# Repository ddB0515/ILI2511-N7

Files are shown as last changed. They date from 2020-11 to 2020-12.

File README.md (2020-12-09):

# ILI2511-N7

Nexus 7(2nd gen) touch controller board based on Ilitek 2511 (only USB and I2C is supported)

# Interactive BOM
[Interactive BOM](http://htmlpreview.github.io/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)

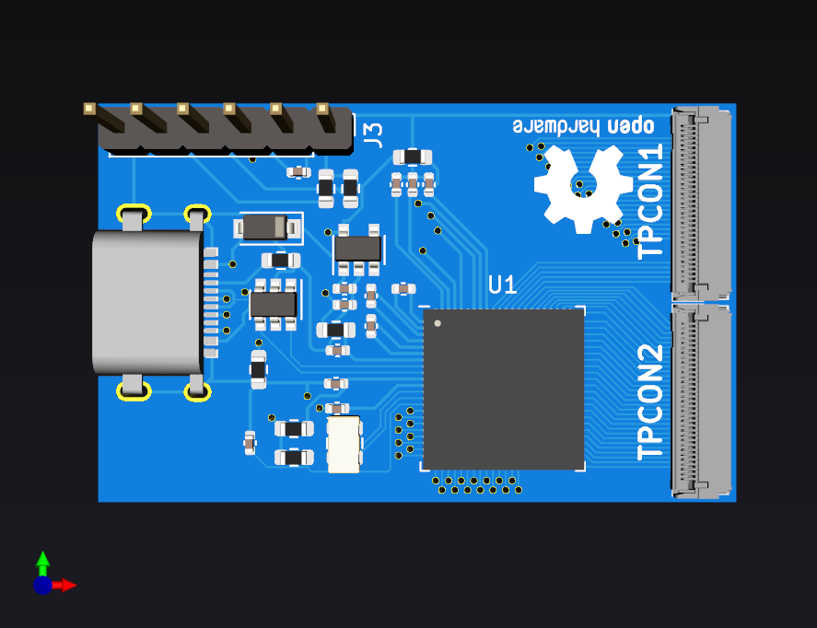
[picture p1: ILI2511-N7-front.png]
Front Photo


## LOG
* v1 inital version
* v2 updated FPC connector (got it working)
* v3 updated footprint to get easier solder and visual check 

## Revisions

 * v1 is currently in testing stage (waiting board to arrive so can test it)
 will update progress here later on
 * v2 working prototype (need slight biggger foorptint for ILI2511)
 * v3 updated footprint and new routing 

## Licence

 * Hardware in this repository is licenced under CERN OHL v1.2

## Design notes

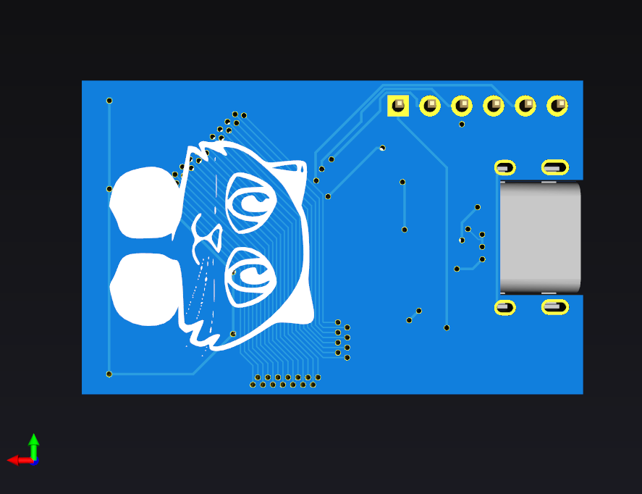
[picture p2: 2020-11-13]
ILI2511-N7-back.png

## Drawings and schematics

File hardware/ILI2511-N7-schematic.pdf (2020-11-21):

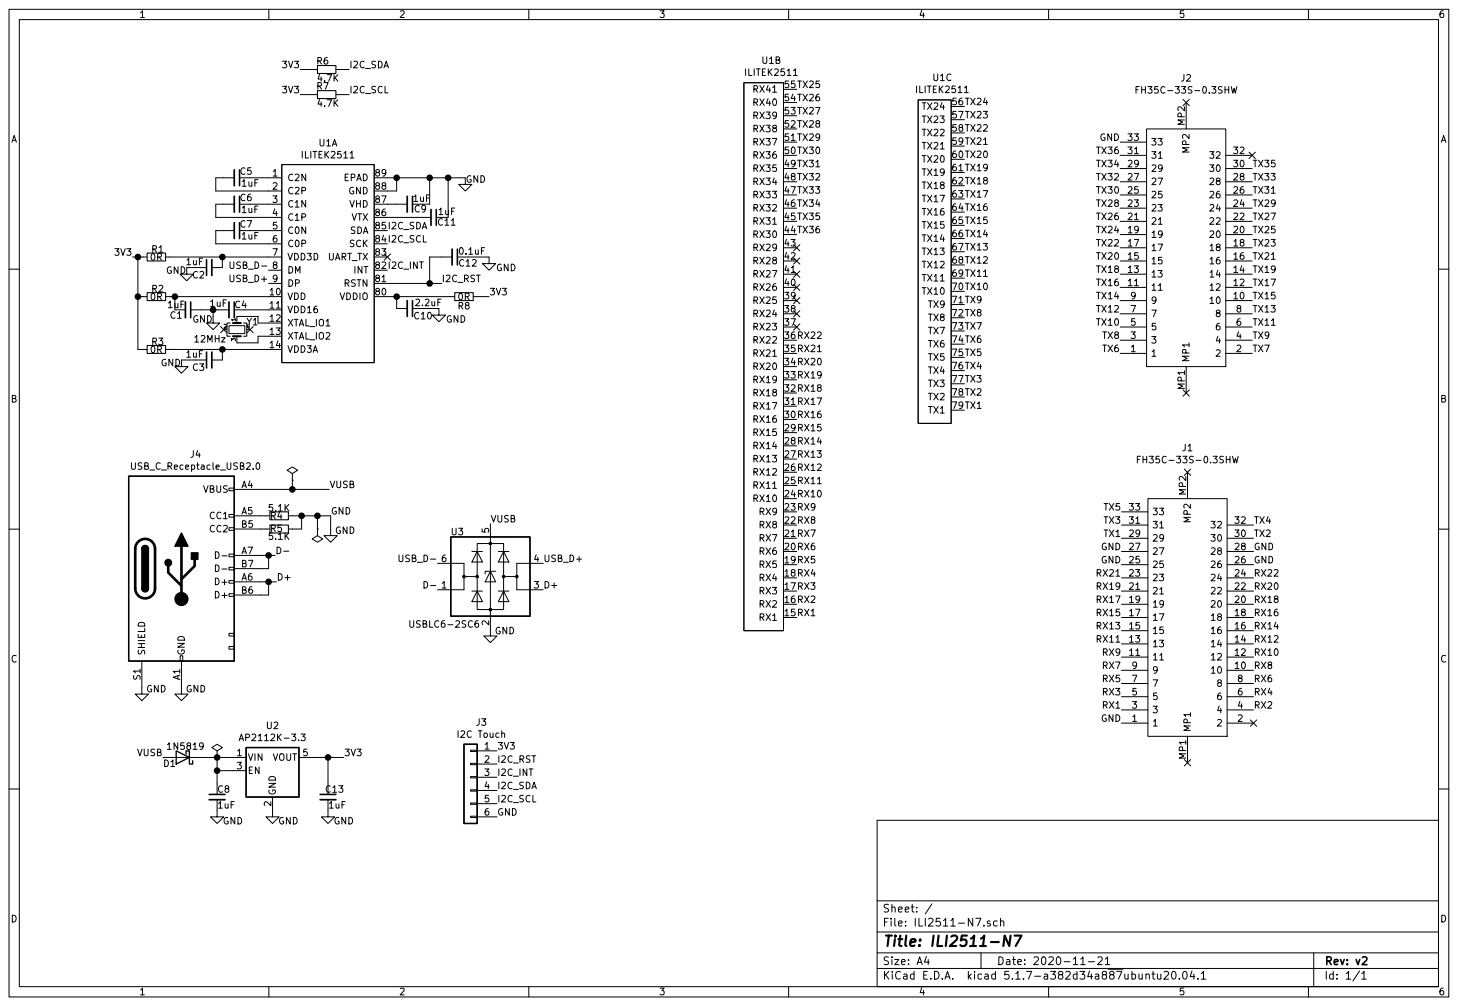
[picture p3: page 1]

File: ILI2511-N7.sch Sheet: / GND

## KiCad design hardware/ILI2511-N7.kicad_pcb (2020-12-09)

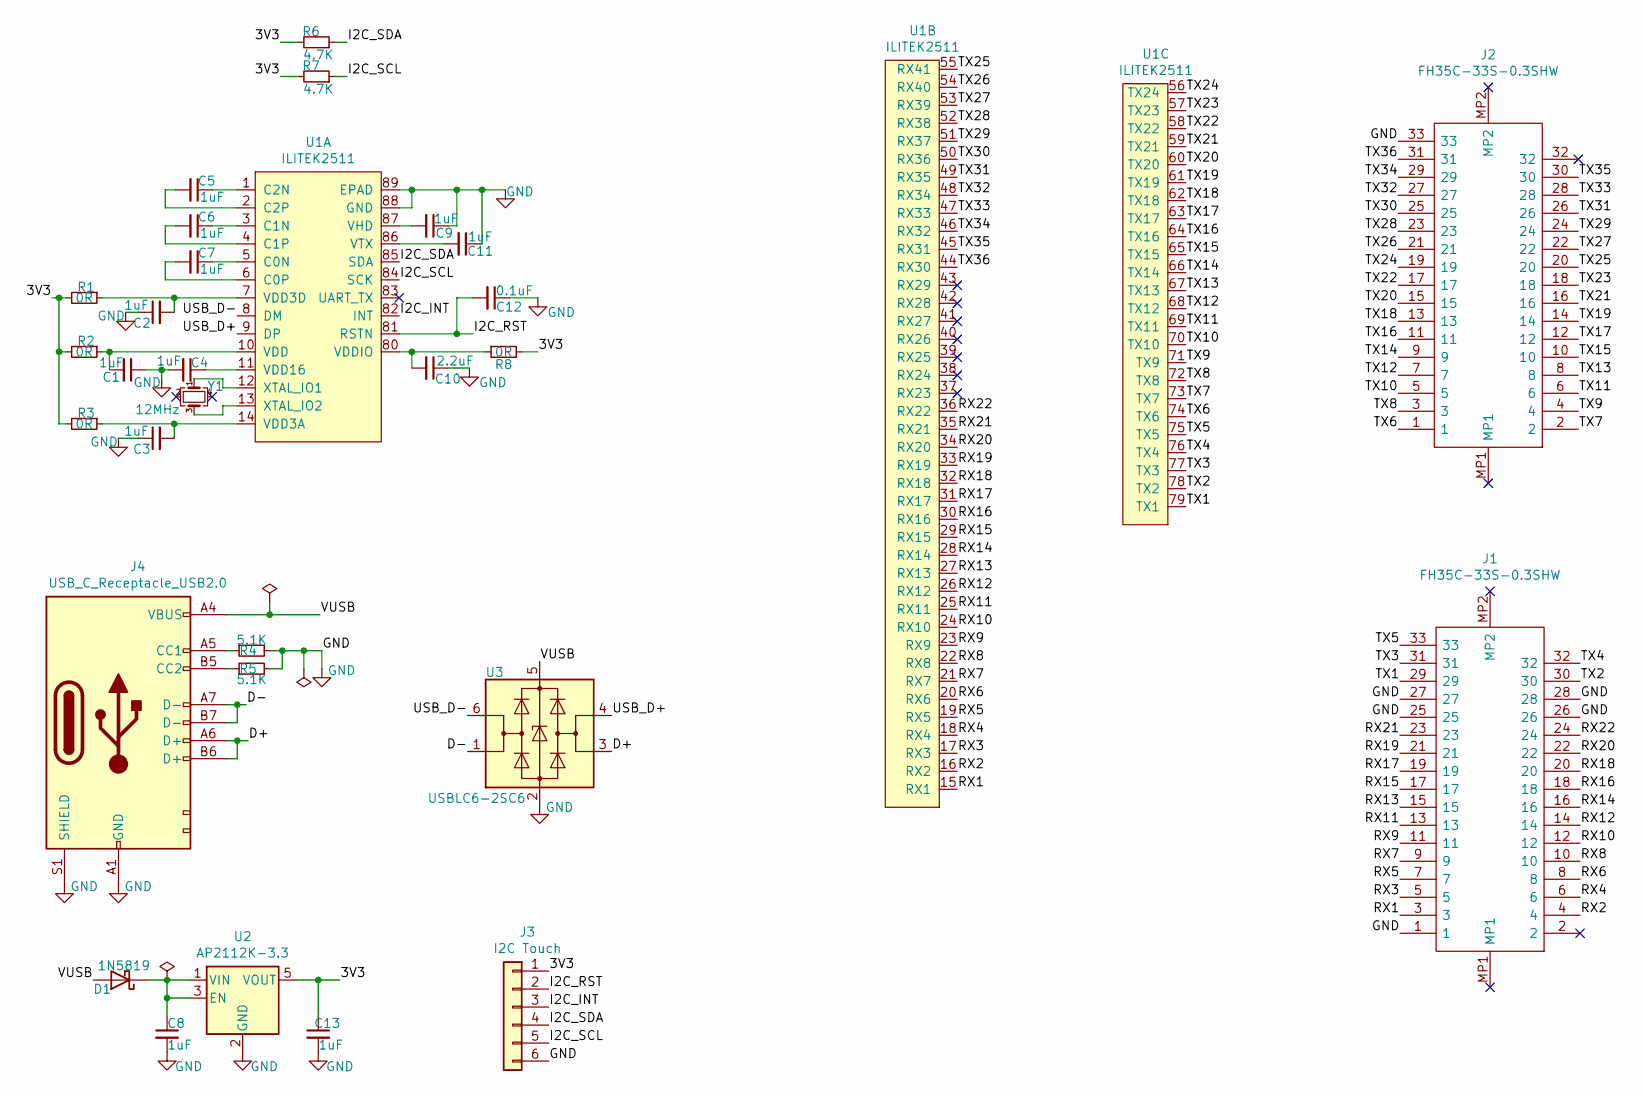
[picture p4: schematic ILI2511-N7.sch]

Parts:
C1, C2, C3, C4, C5, C6, C7, C8, C9, C11, C13: 1uF; C_0402_1005Metric
C10: 2.2uF; C_0402_1005Metric
C12: 0.1uF; C_0402_1005Metric
D1: 1N5819; D_SOD-123
J1, J2: FH35C-33S-0.3SHW; FH35C33S03SHW; Mouser Part Number 798-FH35C33S03SHW99
J3: I2C Touch; PinHeader_1x06_P2.54mm_Vertical
J4: USB_C_Receptacle_USB2.0; USB-C_C168688
R1, R2, R3, R8: 0R; R_0603_1608Metric
R4, R5: 5.1K; R_0603_1608Metric
R6, R7: 4.7K; R_0603_1608Metric
U1: ILITEK2511; ILITEK-2511
U2: AP2112K-3.3; SOT-23-5
U3: USBLC6-2SC6; SOT-23-6
Y1: 12MHz; Oscillator_SMD_ECS_2520MV-xxx-xx-4Pin_2.5x2.0mm

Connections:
/3V3: C13.1, J3.1, R1.2, R2.2, R3.2, R6.2, R7.2, R8.2, U2.5 (VOUT)
/D+: J4.A6 (D+), J4.B6 (D+), U3.3 (I/O2)
/D-: J4.A7 (D-), J4.B7 (D-), U3.1 (I/O1)
/I2C_INT: J3.3, U1.82 (INT)
/I2C_RST: C12.2, J3.2, U1.81 (RSTN)
/I2C_SCL: J3.5, R7.1, U1.84 (SCK)
/I2C_SDA: J3.4, R6.1, U1.85 (SDA)
/RX1: J1.3, U1.15 (RX1)
/RX2: J1.4, U1.16 (RX2)
/RX3: J1.5, U1.17 (RX3)
/RX4: J1.6, U1.18 (RX4)
/RX5: J1.7, U1.19 (RX5)
/RX6: J1.8, U1.20 (RX6)
/RX7: J1.9, U1.21 (RX7)
/RX8: J1.10, U1.22 (RX8)
/RX9: J1.11, U1.23 (RX9)
/RX10: J1.12, U1.24 (RX10)
/RX11: J1.13, U1.25 (RX11)
/RX12: J1.14, U1.26 (RX12)
/RX13: J1.15, U1.27 (RX13)
/RX14: J1.16, U1.28 (RX14)
/RX15: J1.17, U1.29 (RX15)
/RX16: J1.18, U1.30 (RX16)
/RX17: J1.19, U1.31 (RX17)
/RX18: J1.20, U1.32 (RX18)
/RX19: J1.21, U1.33 (RX19)
/RX20: J1.22, U1.34 (RX20)
/RX21: J1.23, U1.35 (RX21)
/RX22: J1.24, U1.36 (RX22)
/TX1: J1.29, U1.79 (TX1)
/TX2: J1.30, U1.78 (TX2)
/TX3: J1.31, U1.77 (TX3)
/TX4: J1.32, U1.76 (TX4)
/TX5: J1.33, U1.75 (TX5)
/TX6: J2.1, U1.74 (TX6)
/TX7: J2.2, U1.73 (TX7)
/TX8: J2.3, U1.72 (TX8)
/TX9: J2.4, U1.71 (TX9)
/TX10: J2.5, U1.70 (TX10)
/TX11: J2.6, U1.69 (TX11)
/TX12: J2.7, U1.68 (TX12)
/TX13: J2.8, U1.67 (TX13)
/TX14: J2.9, U1.66 (TX14)
/TX15: J2.10, U1.65 (TX15)
/TX16: J2.11, U1.64 (TX16)
/TX17: J2.12, U1.63 (TX17)
/TX18: J2.13, U1.62 (TX18)
/TX19: J2.14, U1.61 (TX19)
/TX20: J2.15, U1.60 (TX20)
/TX21: J2.16, U1.59 (TX21)
/TX22: J2.17, U1.58 (TX22)
/TX23: J2.18, U1.57 (TX23)
/TX24: J2.19, U1.56 (TX24)
/TX25: J2.20, U1.55 (RX41)
/TX26: J2.21, U1.54 (RX40)
/TX27: J2.22, U1.53 (RX39)
/TX28: J2.23, U1.52 (RX38)
/TX29: J2.24, U1.51 (RX37)
/TX30: J2.25, U1.50 (RX36)
/TX31: J2.26, U1.49 (RX35)
/TX32: J2.27, U1.48 (RX34)
/TX33: J2.28, U1.47 (RX33)
/TX34: J2.29, U1.46 (RX32)
/TX35: J2.30, U1.45 (RX31)
/TX36: J2.31, U1.44 (RX30)
/USB_D+: U1.9 (DP), U3.4 (I/O2)
/USB_D-: U1.8 (DM), U3.6 (I/O1)
/VUSB: D1.2 (A), J4.A4 (VBUS), U3.5 (VBUS)
GND: C1.1, C2.1, C3.1, C4.2, C8.2, C9.1, C10.1, C11.1, C12.1, C13.2, J1.1, J1.25, J1.26, J1.27, J1.28, J2.33, J3.6, J4.A1 (GND), J4.S1 (SHIELD), R4.2, R5.2, U1.88 (GND), U1.89 (EPAD), U2.2 (GND), U3.2 (GND)
unnamed: C1.2, R2.1, U1.10 (VDD)
unnamed: C2.2, R1.1, U1.7 (VDD3D)
unnamed: C3.2, R3.1, U1.14 (VDD3A)
unnamed: C4.1, U1.11 (VDD16)
unnamed: C5.1, U1.1 (C2N)
unnamed: C5.2, U1.2 (C2P)
unnamed: C6.1, U1.3 (C1N)
unnamed: C6.2, U1.4 (C1P)
unnamed: C7.1, U1.5 (C0N)
unnamed: C7.2, U1.6 (C0P)
unnamed: C8.1, D1.1 (K), U2.1 (VIN), U2.3 (EN)
unnamed: C9.2, U1.87 (VHD)
unnamed: C10.2, R8.1, U1.80 (VDDIO)
unnamed: C11.2, U1.86 (VTX)
unnamed: J4.A5 (CC1), R4.1
unnamed: J4.B5 (CC2), R5.1
unnamed: U1.12 (XTAL_IO1), Y1.1
unnamed: U1.13 (XTAL_IO2), Y1.3

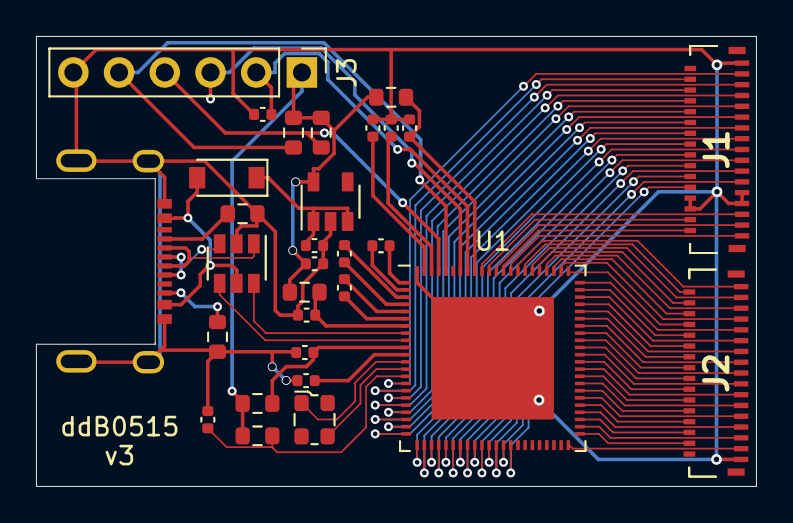
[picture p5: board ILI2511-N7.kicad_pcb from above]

Board: 2 copper layers, 40.0 x 25.0 mm, 30 parts (0 on the bottom side), 87 nets.

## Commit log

2020-11-13 initial push, finished v1
    [ILI2511-N7-B_Cu.gbl, ILI2511-N7-B_Mask.gbs, ILI2511-N7-B_SilkS.gbo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]
2020-11-16 added Interactive BOM
    [ILI2511-N7.kicad_pcb]
2020-11-21 added v2 with Hirose connector (as Molex was not good choice)
    [ILI2511-N7-B_Cu.gbl, ILI2511-N7-B_Mask.gbs, ILI2511-N7-B_SilkS.gbo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]
2020-11-21 deleted schematic(moved to hardware folder)
2020-12-09 updated PCB footprint and new routing
    [ILI2511-N7.kicad_pcb]
